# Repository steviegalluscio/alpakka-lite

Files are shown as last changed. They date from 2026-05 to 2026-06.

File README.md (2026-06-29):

# Alpakka Lite
Add **Dual-gyro** and **Thumb-sense** (gyro on/off) to a regular wired XInput gamepad to build an [Input Labs Alpakka](https://inputlabs.io/alpakka) compatible gyro game controller from mostly off-the-shelf components.
<br>
<br>
<br>
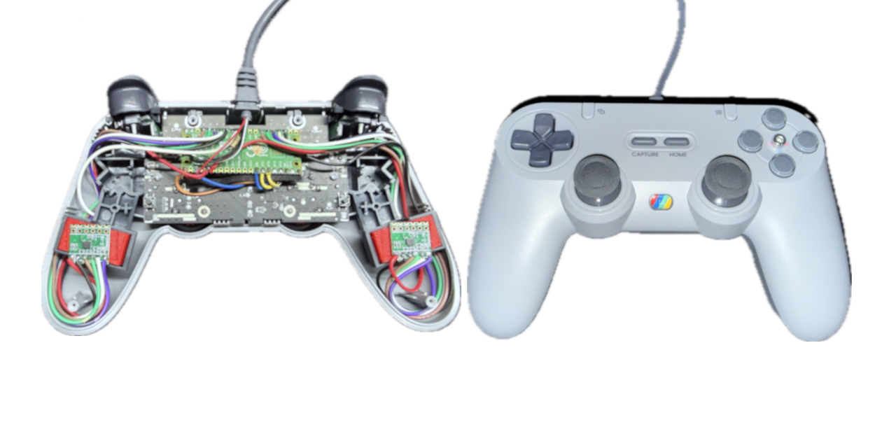
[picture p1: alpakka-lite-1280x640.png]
Alpakka Lite Banner


### Features:
- Lightweight (150g)
- Low-cost ($25 to $50 USD, See full [BOM](./hardware/BOM.md))
- Alpakka compatible firmware, fully configurable with <a href="https://ctrl.inputlabs.io/" target="_blank">ctrl.inputlabs.io</a>
- Dual SPI channel support for gyros
- LSM6DSV IMU support (better than LSM6DSR)
- Capacitive touch gyro on/off
- USB host "passthrough" for XInput Gamepads
- Paddles, capture, and mode buttons working (_only supported for Tegenaria controller_)
- Improved polling and XInput report scheduling.

### Project Links:
- [Parts List](./hardware/BOM.md)
- [Build Guide](./hardware/GUIDE.md)
- [Wiring Reference](./hardware/WIRING.md)
- [Firmware Source](https://github.com/steviegalluscio/alpakka_firmware/tree/alpakka-lite)

## Disclaimer
_This project is an independent initiative and is not affiliated with, endorsed by, sponsored by, or otherwise officially connected to Input Labs Oy. All trademarks and registered trademarks are the property of their respective owners._

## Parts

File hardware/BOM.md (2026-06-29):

# Alpakka Lite
## Bill of Materials (BOM)
| Part | Description | Quantity  | Cost (USD)  | Notes |
| :--- | :--- | :--- | :--- | :---|
| Raspberry Pi Pico | Microcontroller | 1 | $7 | 2pcs for $14 with overnight delivery |
| LSM6DSV breakout | IMU sensor | 2x | $16 (Total) | Preferred IMU. I could only find here https://www.aliexpress.us/item/3256811400904011.html|
| GameSir Tegenaria Lite | XInput gamepad | 1 | $10-$20 | Found on sale for $10 free shipping (Other XInput controllers can work, corded is easiest to solder) |
| M3x8mm hex screw | Touch surface | 1 | ~$0 | Perfect fit but can be any conductive screw |
| 100K ohm resistor | Touch sensor | 1 | ~$0 | If you don't have one, get a set for ~$4 |
| ~7" 22-24 AWG stranded wire | Wiring | 14x | ~$1 (Total) | Buy rainbow cable or cut cheap breadboard jumpers |
|[rumble_mount_left.stl](rumble_mount_left.stl)| Left IMU mount | 1 |  ~$0 |Easy 3D print, ask a friend or use hot glue and wing the mounting  |
|[rumble_mount_right.stl](rumble_mount_right.stl)| Right IMU mount  | 1 |  ~$0 | |

> **Total Cost:** Under $25 USD if you are patient when sourcing. Under $50 is very easy.

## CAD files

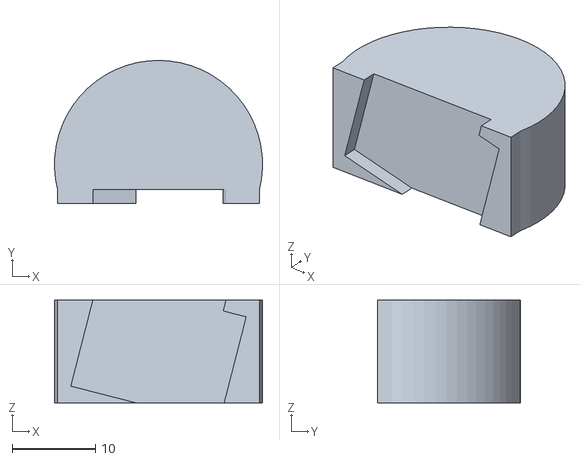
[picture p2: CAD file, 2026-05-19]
hardware/rumble_mount_right.stl
25.0 x 17.2 x 12.4

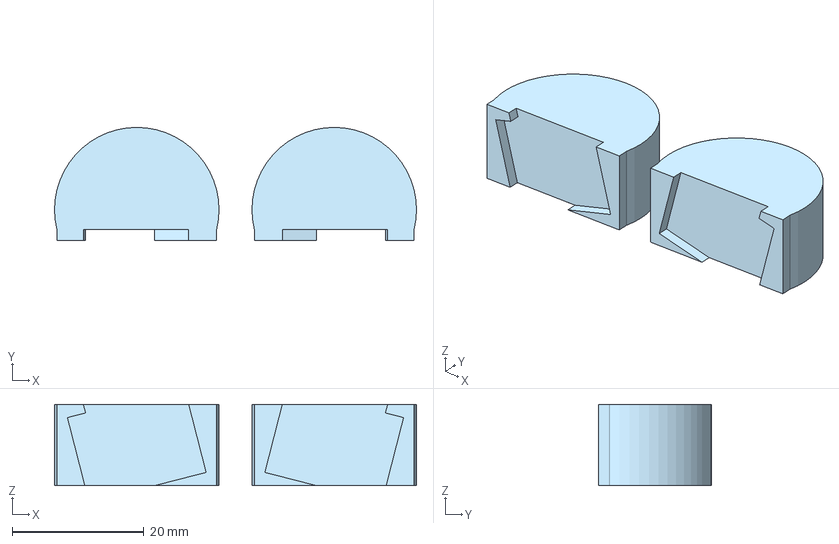
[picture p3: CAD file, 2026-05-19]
hardware/rumble_mounts.step
55.0 x 17.2 x 12.4 mm

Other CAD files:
hardware/rumble_mount_left.stl

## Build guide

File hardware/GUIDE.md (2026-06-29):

# Alpakka Lite
## Build Guide
1) Remove screws and take back cover off of controller.
2) Desolder the left and right rumble motors from the PCB and remove the motors by pulling straight out.
3) Remove the remaining screws from the PCB then fully disassemble the controller.
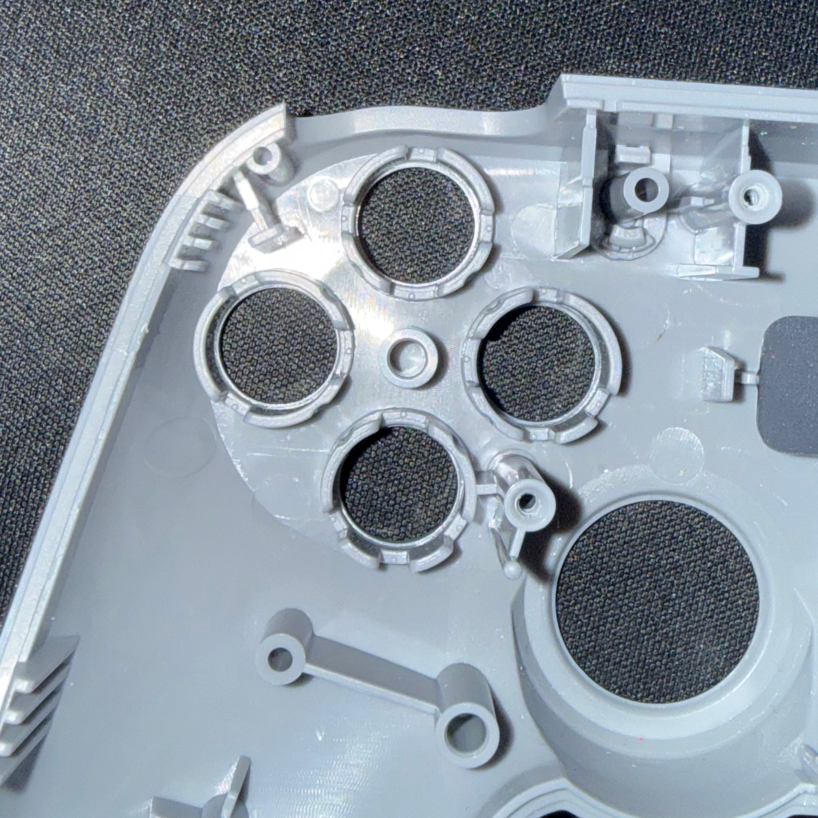
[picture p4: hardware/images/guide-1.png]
inside front cover
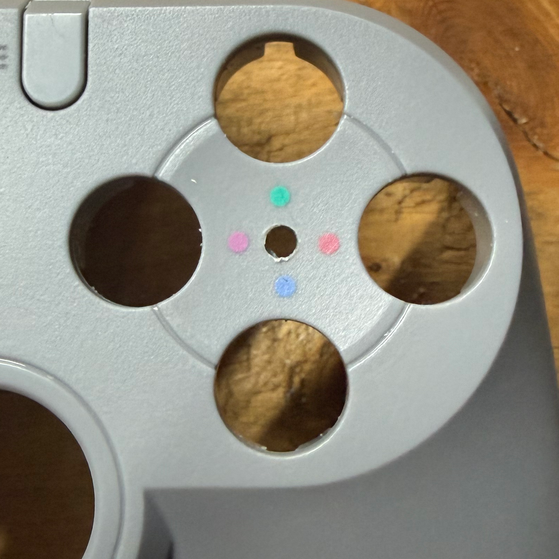
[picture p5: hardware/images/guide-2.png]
drill hole
4) Drill out the hole from inside the front cover in the center of the thumb buttons. <table><tr><td></td><td></td></tr></table>
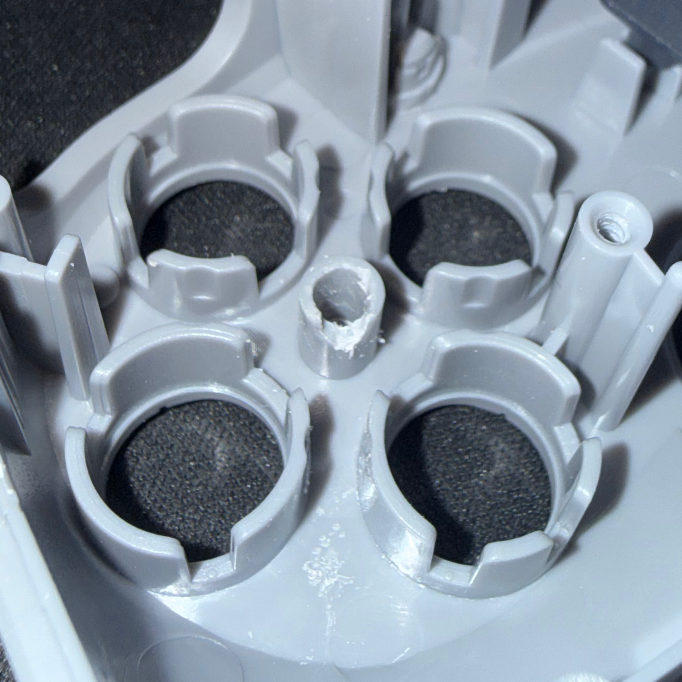
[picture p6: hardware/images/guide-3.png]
file notch
5) File a notch on the same post down and to the left. <table><tr><td></td></tr></table>
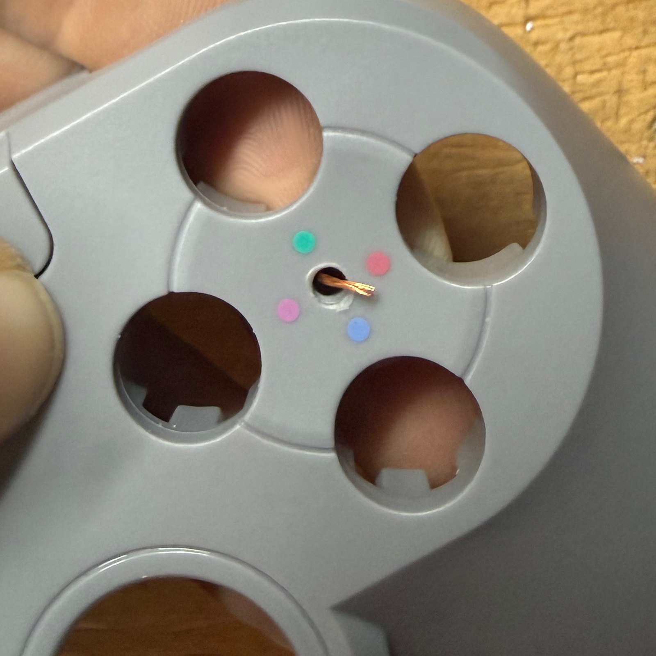
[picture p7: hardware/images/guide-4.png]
wire in hole
6) Strip a section end off of a wire and feed it through the hole from inside to out. <table><tr><td></td></tr></table>
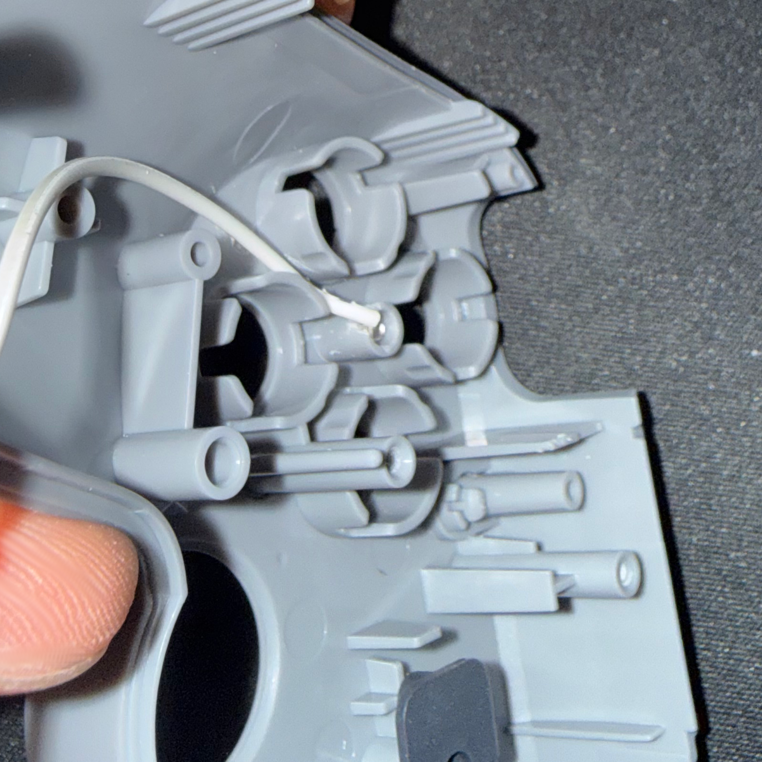
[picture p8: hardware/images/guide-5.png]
thumb screw wire
7) Screw in thumb screw. <table><tr><td></td></tr></table>
8) Partially reassemble controller but leave the backplate off.
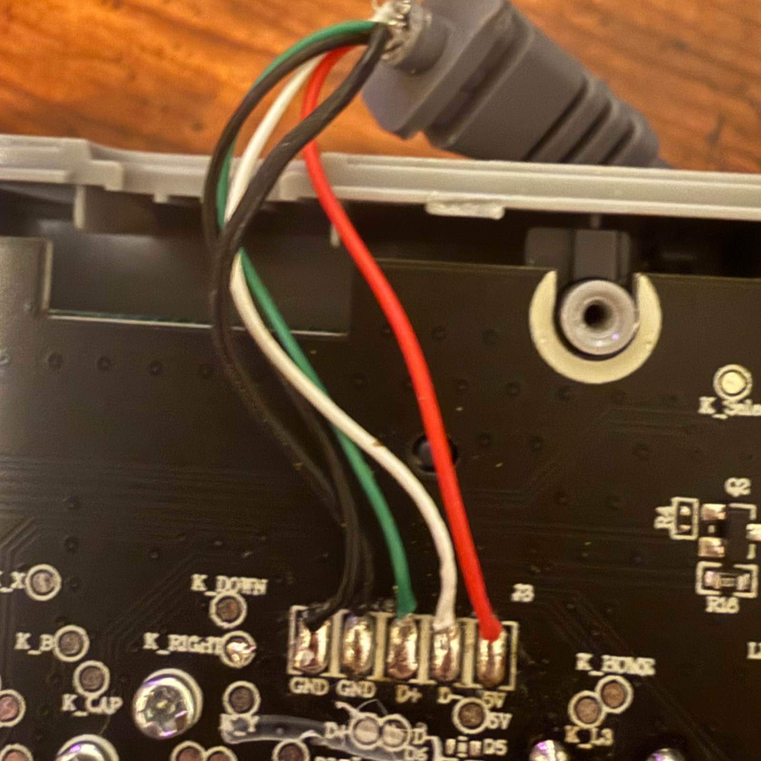
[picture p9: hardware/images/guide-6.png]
9) Desolder the USB cord. (Check for firmware updates one last time before this) <table><tr><td></td></tr></table>
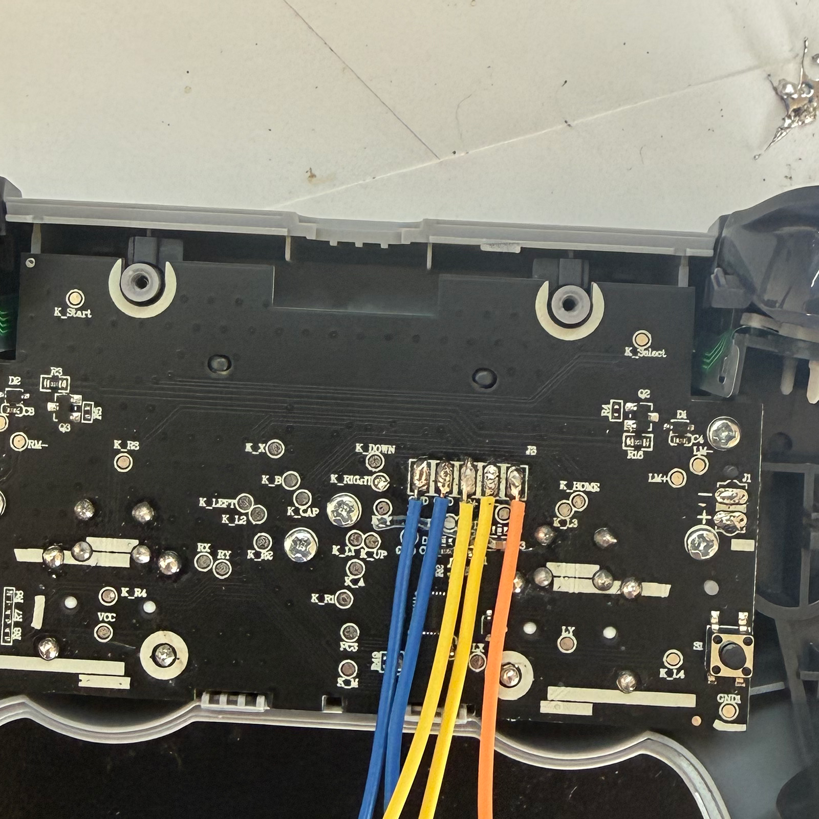
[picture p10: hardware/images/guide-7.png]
10) Solder wires pointing downwards: 4x short 1"-2" wires to GND, GND, D+, D-, and 1x longer 3"-4" wire to 5V. <table><tr><td></td></tr></table>
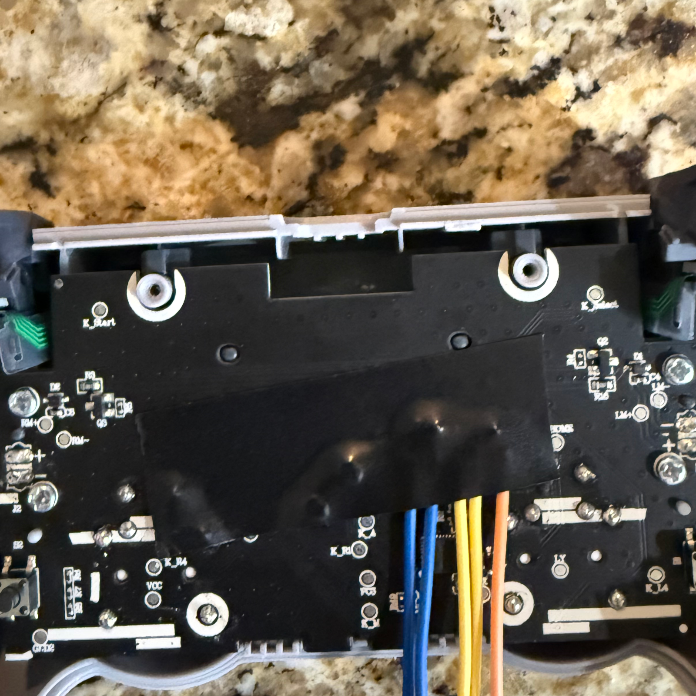
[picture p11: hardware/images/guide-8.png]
tape on pcb
11) Put muliple layers of electrical tape and/or automotive harness tape over the pins and screws. This will protect from shorts later. <table><tr><td></td></tr></table>
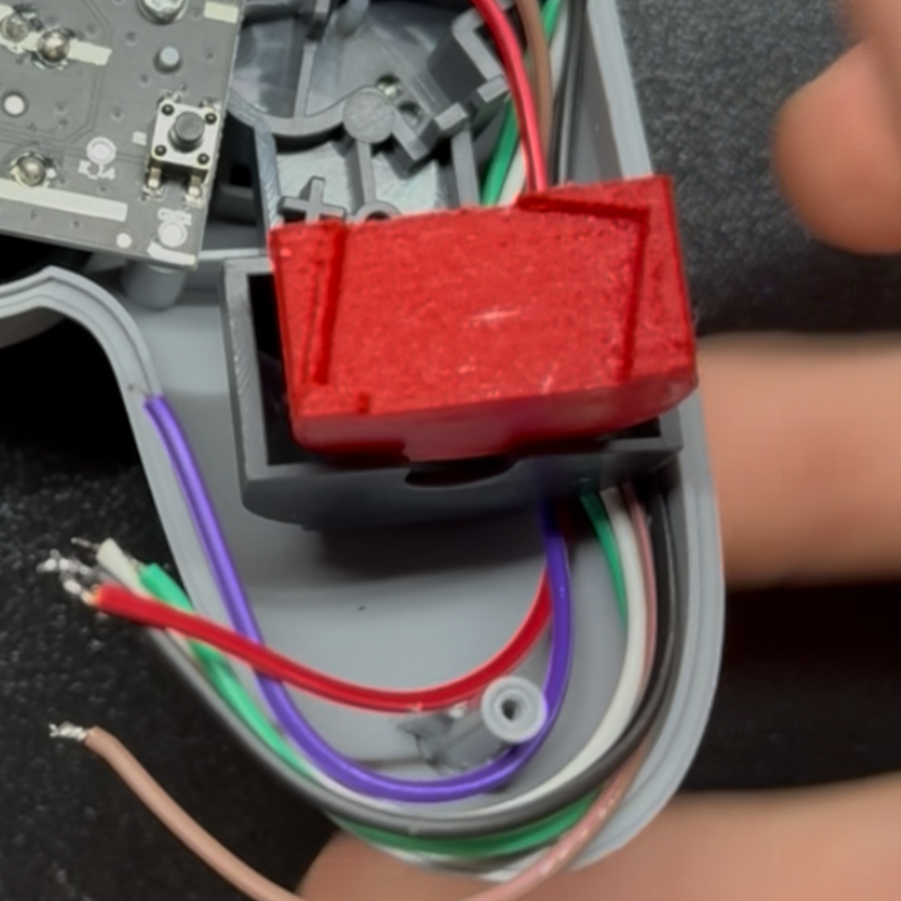
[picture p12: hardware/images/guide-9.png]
rumble mount
12) Press fit the left and right rumble mounts into the motor holders. <table><tr><td></td></tr></table>
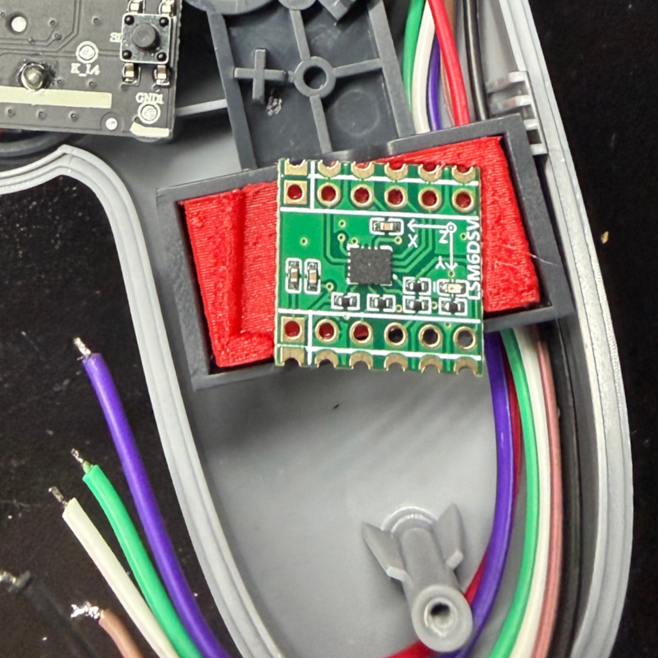
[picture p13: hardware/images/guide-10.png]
imu mount
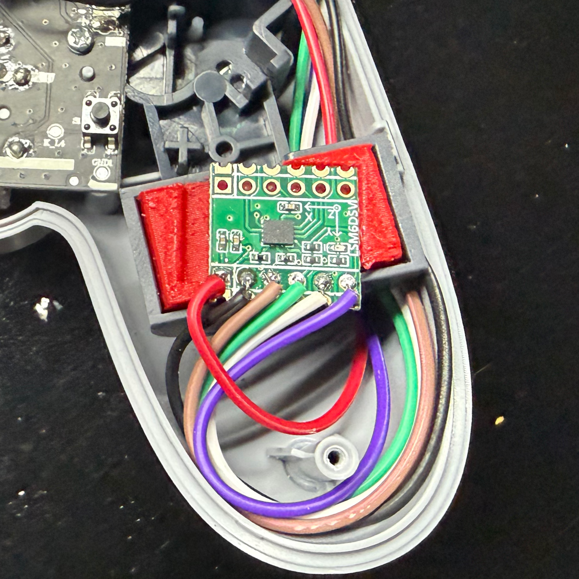
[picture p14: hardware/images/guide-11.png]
imu wiring
13) With a dab of hot glue, mount the left and right IMUs. Then solder ~7" wires to 3V3, GND, SCL, SDA, CS, and SAO. Then, run the wires up and underneath as shown. <table><tr><td></td><td></td></tr></table> _Note: rubbing alcohol makes hot glue pop right off._
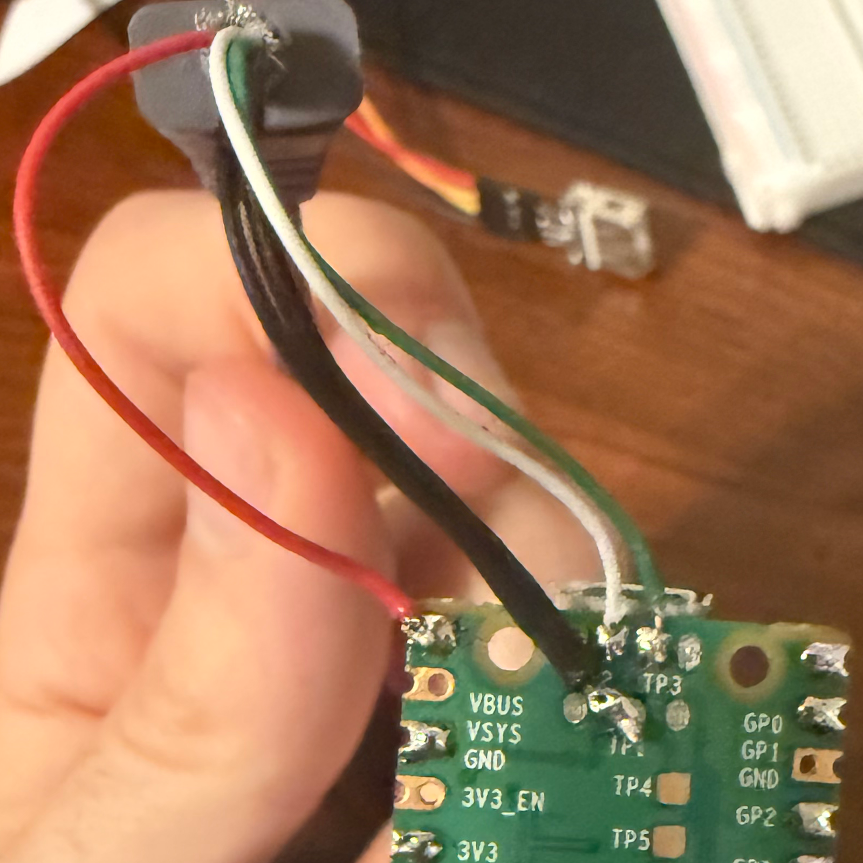
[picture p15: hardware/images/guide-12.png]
14) Solder the USB cord to the pico<table><tr><td></td></tr></table>
15) Hold BOOTSEL button, plug in USB cord, and flash firmware by drag and droping the .uf2 file from [releases](https://github.com/steviegalluscio/alpakka-lite/releases). After the intial flash you can use <a href="https://ctrl.inputlabs.io/" target="_blank">ctrl.inputlabs.io</a> to put the controller into BOOTSEL mode and flash updates.
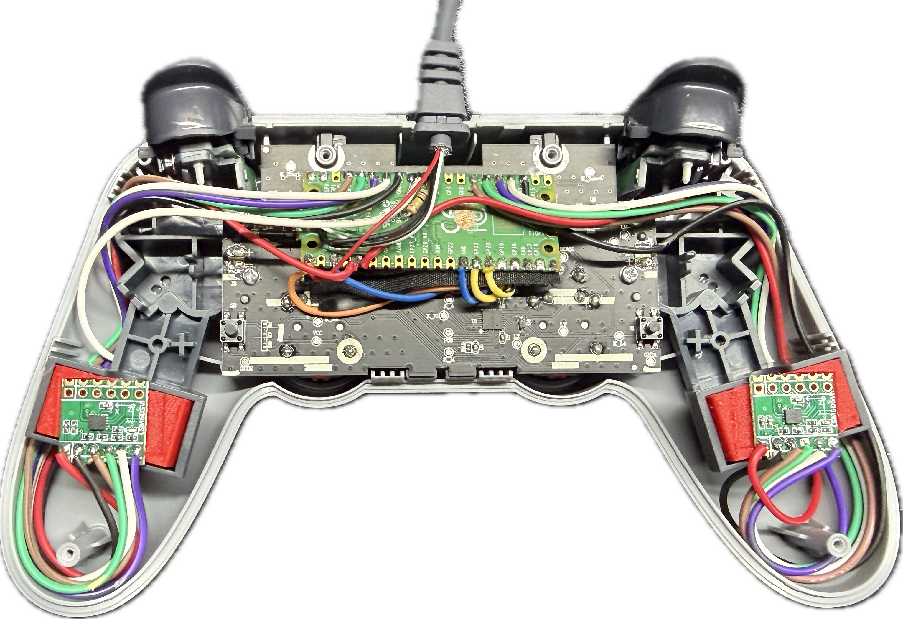
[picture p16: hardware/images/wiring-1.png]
Alpakka Lite Wiring
16) Solder the pins according to [WIRING.md](./WIRING.md). Start with the controller PCB wires along the bottom of the pico first then use a blob of hot glue to hold the pico in place. Curved locking forceps or helping hands will make it easier especially where there are multiple wires sharing a pin. 
17) Guide the wires as seen above and take your time when snapping on the back cover to make sure that no wires are pinched and that the paddle buttons are not blocked. Replace screws in back cover.
19) Enjoy gyro gaming and leave a star :star: on the repo.

<br/>
<br/>

## Troubleshooting
1) Check that your gamepad is in XInput/Xbox 360 mode. (For Tegenaria you have to do this once: hold HOME+X until green light)
2) When testing with a gamepad tester app, [switch to a profile](https://inputlabs.io/alpakka/manual/profiles) like "Console" the default is "FPS Fusion" and uses keyboard.
3) Check that the D+ and D- pins are not swapped and that you don't have any shorts or cold solder joints anywhere.

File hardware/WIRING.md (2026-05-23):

# Alpakka Lite
## Wiring
| Pin | Destination | Notes |
| --- | --- | --- |
| GPIO 2 | Left IMU SCL (SCK)  |  |
| GPIO 3 | Left IMU SDA (MOSI) |  |
| GPIO 4 | Left IMU SAO (MISO) |  |
| GPIO 5 | Left IMU CS  |  |
| GPIO 6 | Touch OUT | Short to GPIO 7 via 100k ohm |
| GPIO 7 | Touch IN | Wire to thumbscrew |
| GPIO 10 | Right IMU SCL (SCK)  |  |
| GPIO 11 | Right IMU SDA (MOSI) |  |
| GPIO 12 | Right IMU SAO (MISO) |  |
| GPIO 13 | Right IMU CS  |  |
| VBUS | USB 5V  |  Controller PCB  |
| VBUS | USB 5V (Red)  | Controller cable  |
| TP1 | USB GND (Black)| Controller cable  |
| TP2 | USB D- (White) | Controller cable  |
| TP3 | USB D+ (Green) | Controller cable  |
| 3V3 | Left IMU VIN |  |
| 3V3 | Right IMU VIN  |  |
| GPIO 20 | USB D- | Controller PCB |
| GPIO 21 | USB D+ | Controller PCB |
| GND | USB GND | Controller PCB (2 pads, tie both to same or diff GND) |

See also:
- [Build Guide](./GUIDE.md)
- Pins in firmware: https://github.com/steviegalluscio/alpakka_firmware/blob/88f42c9516ef7bdc2893ddaced1abc7dd2f941d2/src/headers/pin.h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

Alpakka Lite Wiring 1

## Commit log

2026-05-05 Create directories
    [rumble_mount_left_1.0.stl]
2026-05-05 Add BOM
2026-05-05 Add 3D printed IMU mounts to BOM
    Added 3D printed mounts for left and right IMUs to BOM.
2026-05-05 Update wiring docs with pin assignments
    Added detailed wiring table for GPIO and USB connections.
2026-05-13 Add image of wiring
2026-05-13 Update wiring docs with image
2026-05-19 Add LSM6DSV IMU support to README
2026-05-19 Add rumble mount files
    [rumble_mount_left.stl, rumble_mount_right.stl, rumble_mounts.step]
2026-05-19 Add stl file links
    Updated the BOM to include STL file links for 3D printed mounts.
2026-05-19 Revise BOM with lsm6dsv IMU details
    Updated the BOM to reflect changes in IMU sensor options and costs.
2026-05-23 Update formatting for Dual-gyro and Thumb-sense
2026-05-23 Add link to build guide in WIRING.md
2026-06-22 Added instructions for switching gamepad mode before use.
2026-06-29 Update README to remove LSM6DS3 IMU support
    LSM6DS3 is not worth it, much worse than LSM6DSV for similar price
2026-06-29 Update BOM
    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
2026-07-28 Fix phantom button release bug
